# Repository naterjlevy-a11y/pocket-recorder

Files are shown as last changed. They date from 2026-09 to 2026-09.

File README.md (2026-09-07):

# Pocket Recorder

A thing in your pocket. Squeeze it, talk, let go. The note is on your phone
before you've put it away.

This repo is the industrial design and the mechanical packaging for that object,
plus a web app that does the software half. **The hardware is designed and
costed, not built.** Everything below says which is which.

---

## Why it isn't an always-on recorder

The AI wearables on sale right now record continuously, and that one decision
drives every other problem they have. It records everyone around you. It forces
a subscription, because transcribing all day is expensive. It forces a battery
big enough to run all day. And it makes people visibly uncomfortable, which
shows up in the reviews.

Deliberate capture is a different object:

| | Always-on pendant | This |
| --- | --- | --- |
| Privacy | records everyone, always | records only while held |
| Battery | must survive a day of recording | idle 99.9% of the time |
| Transcription cost | hours per day | seconds per day |
| Subscription | structurally required | optional |
| Social friction | high | it's a voice memo button |

It is not a smaller version of the always-on thing. It's the voice memo app,
minus unlocking your phone.

---

## The mechanical problem

The whole design is one question: **does it fit in a bar small enough to forget
you're carrying?**

Target is **6 × 6 × 35 mm** in drawn 316L square tube. Working through it:

| | |
| --- | --- |
| Wall thickness | 0.30 mm — thinner is too fragile to carry a button boss |
| Internal cavity | 5.40 × 5.40 mm |
| Board length needed | **26.2 mm**, parts end to end with routing space |
| Caps and accent band | 9 mm |
| Spent before any battery | **35.2 mm** |

That last row is the answer to why the bar isn't 40 mm long and why the battery
is a custom stepped pouch rather than a cell: at 40 mm there is no room left for
power. The battery becomes a 4.6 mm thick step above the board and a 2.6 mm thin
step beneath it, which is what buys **3.7 hours** of talk time at a realistic
6 mA and leaves **0.67 mm** of headroom on the stack.

Every component sits at a real coordinate in [`model/bar.scad`](model/bar.scad),
which renders five ways — assembled, ghost, internals, section, exploded — so
the packing can actually be looked at rather than asserted.

### What went wrong

[`ERRATA.md`](model/ERRATA.md) is an audit of the design against itself. It found
eight errors, three of them serious. The worst:

> **The button does not work. The design is wrong.** The tactile switch is placed
> facing the front face; the pusher enters through the side face. They are
> perpendicular. The pusher would press into empty space beside the switch.

That is a geometry error that survived both the model and the parts document,
and it would have been found by a machinist or by a wasted prototype run. It is
written up rather than quietly fixed because the fix has two options with
different costs, and the choice isn't made yet.

---

## What's in here

| | |
| --- | --- |
| [`model/bar.scad`](model/bar.scad) | The parametric model. Open in OpenSCAD, change `VIEW`. |
| [`model/PARTS-AND-LAYOUT.md`](model/PARTS-AND-LAYOUT.md) | Every part with an order number, at a real coordinate, summed and checked. |
| [`model/FIT-STUDY.md`](model/FIT-STUDY.md) | Whether it fits at 5 mm and 6 mm, and what sets the wall thickness. |
| [`model/ERRATA.md`](model/ERRATA.md) | The audit. Eight errors, three serious. |
| [`model/ASSEMBLY.md`](model/ASSEMBLY.md) | Build order. |
| [`model/SHOPPING-LIST.md`](model/SHOPPING-LIST.md) | What to buy, with confidence marked per line. |
| [`model/renders/`](model/renders) | Outside, inside, sectioned, exploded. |
| [`app/index.html`](app/index.html) | The software half: hold, talk, release, note lands. |
| [`PLAN.md`](PLAN.md) | The product argument and the market it's aimed at. |

## Running the app half

`app/index.html` is a single file with no build step. Open it, or serve the
folder:

```bash
python3 -m http.server 8000 --directory app
```

## Status

Designed, costed and audited. Not manufactured. The parts list carries a
confidence mark per line because the next step spends money.

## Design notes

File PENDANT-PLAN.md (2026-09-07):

# The Bar — plan

**One line:** a slim steel bar on a chain. It looks like jewellery. Tap it, talk, let go.

Supersedes the pocket form factor in `PLAN.md`. The thesis, the software half, and the legal notes there still hold.

---

## 1. The thesis: Ray-Ban Meta logic

You walked into a Ray-Ban store with $430 wanting nice glasses. You left with smart glasses. **The tech was a bonus discovered after the object had already won.**

That is the entire strategy. Every competitor inverts it — they build a gadget, then try to make it wearable.

| | Them | This |
| --- | --- | --- |
| First impression | "what's that device?" | "nice chain" |
| Bought because | it records | it looks good |
| Worn when | you remember to | always, it's your chain |
| Off-mode | looks like a gadget | looks like jewellery |

**The test:** someone should be able to wear it for a week before anyone asks what it is. If it fails that, nothing else in this document matters.

Corollary: **it must look complete with the electronics dead.** A bar with a seam, a visible port, or a blinking LED is a gadget. Battery flat, it still has to read as a $200 chain.

---

## 2. The object

```
         ○ ── stainless chain (or leather cord)
         │
       ╔═╧═╗
       ║   ║   6 × 6 mm square section
       ║   ║   60 mm long
       ║   ║   brushed or polished 316L
       ║   ║   no visible seam, no port, no LED
       ╚═══╝
```

| Spec | Target | Note |
| --- | --- | --- |
| Section | **6 × 6 mm** | 5 mm is possible — see §4. 6 mm is the shippable one |
| Length | 55–65 mm | also happens to be a λ/2 antenna at 2.4 GHz |
| Weight | 12–18 g | heavy enough to feel real, light enough to forget |
| Material | 316L steel v1, titanium v2 | drawn square tube, not machined |
| Finish | brushed + polished SKUs | |
| Water | **IP68** | the differentiator — see §5 |
| Cord | steel chain **or leather** | leather is quieter, see §6 |

**Chain lug is a machined solid end cap, never a hole in the tube wall.** At 0.3 mm wall that's where a yanked necklace fails.

### 2a. The reference object — real dimensions

**"Slim Bar Pendant", stainless steel: 40 mm long × 4 mm wide. Shiny finish. 10:1 ratio.**

That's the target aesthetic, confirmed from the spec sheet rather than estimated. It is smaller than it looks in the worn photo.

**4 × 4 × 40 mm cannot hold this product.** At 0.3 mm wall the cavity is 3.4 mm, and the minimum PCB width is 3.3 mm — 0.05 mm of clearance per side, before an insulating liner. There is no room for a battery *beside* the board, only end-to-end, which leaves ~11 mAh. That's Oura-ring capacity, and Oura isn't recording audio.

**The move is to scale the object, not change its proportion.** The 10:1 ratio is the look; hold it and grow.

| Outer | Cavity | Battery | Ratio | |
| --- | --- | --- | --- | --- |
| 4 × 4 × 40 | 3.4 | ~11 mAh | 10:1 | ← the reference. Unbuildable |
| 4 × 4 × 55 | 3.4 | ~23 mAh | 14:1 | too spindly, board still impossible |
| 5 × 5 × 55 | 4.4 | ~38 mAh | 11:1 | aggressive but real |
| **6 × 6 × 60** | **5.4** | **~67 mAh** | **10:1** | **← same proportion, 1.5× scale** |
| 7 × 7 × 50 | 6.4 | ~66 mAh | 7:1 | reads stubby |

**Target: 6 × 6 × 60 mm.** Identical 10:1 proportion to the pendant you picked, uniformly scaled 1.5×. It should read as *the same object*, because geometrically it is one — and it carries 6× the battery of the 4 mm version.

Millimetre intuition:

| | |
| --- | --- |
| 4 mm | the reference — a stack of ~5 credit cards |
| 5 mm | thinner than a drinking straw |
| **6 mm** | **a drinking straw** |
| 8 mm | an iPhone's thickness; an Apple Pencil is 8.9 |

**Buy the actual pendant ($40) before deciding.** Hold 4 mm in your hand, then hold a 6 mm steel tube next to it. This decision should be made physically, not from a table.

**Other things the photo settles:**

- **Square section confirmed.** Two faces catch light differently — one bright, one shadowed — with a crisp edge between. It reads as a machined bar, not a round rod. Preserve that edge; it's what makes it look intentional rather than like tubing.
- **Length-to-width ratio is ~8:1.** That proportion *is* the look. Get thicker without getting longer and it becomes a USB stick.
- **It hangs from a small bail and swings freely.** It is not a fixed link in the chain. Free-hanging is the correct choice — a rigid link would fight the body and telegraph "device."
- **The chain is delicate relative to the bar.** ~4 mm links against a 7 mm bar. A heavier chain would make it look like hardware.
- **No seam, no port, no hole anywhere on the visible faces.** Everything — mic port, contacts, antenna break — has to live on the rear face or the end caps.

---

## 3. Interaction

No screen. No LED you can't see on your own chest. Two haptic ticks are the entire UI.

```
tap ──────▶ tick ──▶ recording ──▶ release ──▶ tick ──▶ synced
double-tap ▶ tick tick ──▶ hands-free, records until tapped again
```

**Input is an accelerometer, not a touch sensor.** This is settled by physics, not preference: capacitive and inductive touch-on-metal both work by sensing the metal *flex* under your finger. A 3.5 mm button in a 0.5 mm steel wall deflects **28 nanometres** — about 180× below the detection floor. Those are appliance-panel technologies and they do not scale to a 6 mm bar.

An **ST LIS2DW12** (2 × 2 mm, <1 µA) has a hardware single-tap and double-tap engine that runs while the main chip sleeps. It gives you exactly the interaction you described, and a rigid metal bar is the *best* case for it — metal transmits the tap impulse cleanly. Oura went the same way on titanium rather than fight capacitive sensing.

Free bonus: the mic can confirm taps acoustically. Two-sensor agreement ≈ no false triggers in a pocket or under a coat.

---

## 4. How thin can it actually go

**5 mm is real.** Oura Ring 4 is 7.9 × 2.88 mm — a *smaller* cross-section than 5 × 5 — fully titanium, BLE, 100 m water resistance. Your bar has more internal volume than an Oura ring.

The unlock is **don't machine it, buy tube.** 5 × 5 mm drawn stainless square tube at 0.3 mm wall is a catalogue item (the medical-needle industry stocks it by the mile). That gives a 4.4 × 4.4 mm cavity — 1.12 cm³. Machining titanium to those walls is specialist work; buying tube is not.

| | 5 mm | **6 mm** | 7 mm |
| --- | --- | --- | --- |
| Battery | 32–40 mAh | **~50 mAh** | 70–90 mAh |
| Off-the-shelf cell? | **no — 50–100k MOQ** | **yes** | no |
| PCB | 6-layer HDI, via-in-pad | 4-layer | 4-layer, easy |
| Days @ 45 min/day | ~4 | ~6 | 8–10 |

**One thing forces 6 mm: battery supply.** Below ~4.5 mm cell diameter nothing exists off the shelf except Panasonic 16 mAh pin cells. A custom cell means a 50,000-unit minimum order — a business constraint, not a physics one.

**Decision: prototype at 5 mm to prove the antenna, ship at 6 mm.** On a 60 mm bar nobody perceives the millimetre, and 6 mm is still slimmer than every competitor (Plaud NotePin's *smallest* dimension is 11 mm).

---

## 5. The obstacles, ranked honestly

### 🔴 1. The metal case is a Faraday cage — this is the whole project's risk

A sealed metal tube does not let BLE out. The cavity is a waveguide operating **14× below cutoff**, attenuating **~6 dB per millimetre**. An antenna 5 mm inside the tube is 30 dB down. It is not weak, it is disconnected.

**"Put a chip antenna inside and add a small window" is dead on arrival.** The required RF aperture at 2.4 GHz is roughly half a wavelength — 62 mm. That is the whole product. The window can't be a patch; it has to be the device.

**The fix — the metal becomes the antenna:**

```
╔═════════╗ ← 30 mm steel  ┐
║         ║                │ half-wave dipole,
╠═════════╣ ← 1–2 mm ceramic/NMT band, fed across
║         ║                │ 61 mm ≈ λ/2 at 2.45 GHz
╚═════════╝ ← 30 mm steel  ┘
```

Split the bar, feed differentially across an insulating band. Same architecture as the iPhone 4 frame. Published metal-cased smart-jewellery research measures 68 % efficiency free-space, 27 % worn on a body.

The insulating band can be made by **NMT** (plastic injected into nano-etched metal) which produces the RF break *and* the waterproof seal in one operation.

**Budget for 2–3× range loss vs a plastic case.** Fine for a phone in your pocket. Not fine if you want 10 m. And skin contact detunes it — plan a thin dielectric coating so the radiator never touches you galvanically.

**Prototype this first. Before industrial design, before firmware.** If the split-bar antenna doesn't work, the product is plastic and the whole premise changes.

*Read: Oura patent US 11,349,191 — they make the battery housing itself the radiator.*

### 🟠 2. Battery: 50 mAh is the whole budget

Only push-to-talk makes this possible. Always-on at 5–6 mm would need charging twice a day — that is why every always-on competitor is a fat pendant.

| | |
| --- | --- |
| Standby (~45 µA) | weeks |
| 45 min recording/day | ~6 days |
| Continuous recording | ~5 h |

Storage caps at **32 MB NOR** (no SPI NAND package is small enough) ≈ 3 h of Opus. Conveniently matches the battery, so the design is self-consistent.

### 🟠 3. The microphone, dangling on your chest

Three separate problems:

**a. Structure-borne chain noise.** A metal bar rigidly coupled to a metal chain is a *contact microphone for the chain*. Every link tick goes straight into the diaphragm, louder than your voice.
→ **Never hard-mount the mic.** Suspend it on a compliant silicone boot. Highest-leverage mechanical decision in the build.
→ **Offer a leather cord SKU.** It is dramatically quieter than steel, and it's a legitimate second aesthetic rather than a compromise.

**b. Distance and off-axis.** Sternum to mouth is ~25–30 cm, and the mouth is above and behind. The physics is fine — 69 dB SPL at 30 cm against a 65 dBA-SNR mic is ~40 dB SNR before room noise. The losses are chin/chest shadowing and clothing rustle, not mic sensitivity.
→ **Two mics ~40 mm apart with beamforming** (a wearable array demonstrates ~16.5 dB SNR gain on the wearer's voice). Port angled up.

**c. The acoustic port.** A long narrow tunnel through thick metal becomes a resonator that wrecks the speech band.
→ **0.3 mm drawn tube makes this a non-issue** — Helmholtz lands at ~33 kHz, out of band. Bond the mic directly to the port with a thin gasket. Every extra millimetre of standoff makes it worse.

**Push-to-talk does the rest for free.** The mic is live only while you're deliberately holding still to speak. An always-on device has to survive a jog; this only has to survive standing still for 20 seconds. Gate on the IMU you already have — flag noisy segments rather than silently producing garbage.

### 🟡 4. Charging — you're right about the ritual, wrong about the technology

Your instinct is correct: **people already take chains off at night.** Drop it in a dish, it charges. That ritual is the product's charging story and it's better than a cable.

But true wireless is the wrong way to get it:

| | Verdict |
| --- | --- |
| **Qi** | dead — smallest coils are 10–13 mm, and the metal body kills it |
| **NFC-WLC** (ROHM ML7670, 13.56 MHz) | exists, built for smart rings, but needs ferrite shielding that eats 0.3 mm of a 4.4 mm cavity, and competes with the antenna for the same dielectric window |
| **Magnetic dock + contacts** | **✓ same ritual, a fraction of the risk** |

**A magnetic cradle delivers the exact UX you described** — plop it down, it snaps and charges — with none of the coil problems. Oura ships **exposed charging contacts at 100 m water resistance**, so contacts are not a sealing compromise. Gold or rhodium plating (sweat drives electrolysis on cheap plating), and keep the pads unpowered until the dock detects a valid load.

Bonus: make them **4 contacts** and the dock also becomes your high-speed data offload — 32 MB in ~2 minutes, instead of pushing audio through a metal-attenuated BLE link.

### 🟡 5. Waterproofing — nobody in this category has done it

Limitless Pendant: IP54. Plaud NotePin: no IP rating, explicitly not submersible. **This is an open differentiator**, and it's the difference between "take it off before the shower" and "never think about it."

Parts are off the shelf: **Gore GAW334** acoustic vent, 1.6 mm, IP68-rated, <2 dB loss at 1 kHz. Seam by NMT bond or adhesive plus full epoxy potting — Oura hits 10 ATM with glued shells. **Avoid O-rings**; there's no room for a gland in a 0.3 mm wall.

### 🟡 6. Recording law

Unchanged from `PLAN.md` §8. Canada is one-party. California, Washington, Illinois, Florida are all-party consent. Deliberate self-capture is the safe case — get the marketing copy right before shipping, not after.

---

## 6. Architecture

```
   ┌── end cap + chain lug (machined solid) ──┐
   │  [ mic A ]                               │  ← compliant boot, ported up
   │  ═══════════════════════════════════════ │
   │  [ nRF54L15 ][ flash ][ LIS2DW12 ][ PMIC ]│  ← 3.5 mm rigid-flex, 4-layer
   │  ═══════════════════════════════════════ │
   │  [ ~50 mAh cell ]                        │
   │  [ mic B ]                               │  ← beamforming pair
   └── ceramic/NMT band = antenna feed ───────┘
          └─ 4 pogo pads on rear face ─┘
```

| Function | Part | Size |
| --- | --- | --- |
| SoC | **Nordic nRF54L15** CSP47 | 2.45 × 2.25 mm |
| | *(nRF52840 WLCSP is 3.5 × 3.6 — too wide. Different chip from `PLAN.md`.)* | |
| Mic ×2 | TDK T5837, flex tail, adhesive-bonded to port | 3.5 × 2.65 × 0.98 |
| Storage | Winbond W25Q128JW WLCSP (16 MB) or MX25U256 (32 MB) | 2.5 × 2.5 |
| Input | ST LIS2DW12 tap engine | 2.0 × 2.0 |
| Power | Nordic nPM1100 | 2.1 × 2.1 |
| Codec | Opus 16 kHz mono, ~20 kbps (nRF54L15 has the RAM; nRF52 didn't) | — |
| Antenna | split-bar dipole fed across ceramic band | — |
| I/O | 4 pogo pads: charge + offload | — |

**Wiring principle: the chain load never reaches a solder joint.** Board floats on a compliant mount inside the tube; lugs tie into machined end caps. Watch-case logic.

**Store and forward, never stream.** BLE carries control and status only — a few hundred bytes that punch through a marginal metal link fine. Audio goes over the dock. A dropped connection mid-sentence must never cost a note.

---

## 6a. The app

**Design goal: the ideal number of app opens per day is zero.** The bar captures, the phone routes, the note lands where it belongs. The app is a safety net you check occasionally — not a destination. Every screen below exists for when something went wrong or you want to look back.

This is the opposite of Plaud, whose app *is* the product and where every note is a trip into their walled garden.

### The happy path — no app involved

```
tap ─▶ "note to self, order the L298N" ─▶ release
  │
  ├─ device: encode, write to flash, BLE notify "1 pending"
  │
  ├─ phone wakes in background (no unlock, no open)
  │    pull audio ─▶ transcribe on-device ─▶ clean ─▶ parse routing phrase
  │
  └─ lands in Apple Notes. Silent. ~10 s after you stopped talking.
```

You never saw a screen. That's the product.

### Screens

**1. Inbox** — the default and usually the only one.

Reverse-chronological cards. Each shows transcript preview, duration, time, and a **destination badge** (`Notes` · `Reminders` · `Claude` · `Unrouted`). Pull to sync. That's it.

The badge is the important bit — it tells you at a glance that the thing already went where it should, so you can close the app.

**2. Note detail** — transcript, audio scrubber, edit, re-route, delete. Raw and cleaned text both available; people distrust cleanup they can't inspect.

**3. Routing rules** — the differentiator, and the only screen worth real design effort.

| Phrase | Destination |
| --- | --- |
| "note to self…" | Apple Notes |
| "remind me to…" | Reminders (parse the time) |
| "hey Claude…" | clipboard / Claude, waiting on the laptop |
| "add to \<list\>…" | that list |
| *(no phrase)* | Inbox, unrouted |

User-editable. Ships with sensible defaults. Fork Cadence's parser.

**4. Device** — battery %, notes pending, storage, last sync, firmware. Boring on purpose. Also where tap sensitivity gets calibrated.

**5. Onboarding** — pair, tap-calibrate (tap it three times so the threshold fits how *you* tap and what you wear it over), choose destinations, record one test note end-to-end. Under two minutes.

### The states that actually matter

Most of the app's difficulty is not screens, it's these:

| State | Behaviour |
| --- | --- |
| Phone out of range | Device holds it. Nothing is lost. Badge shows pending count on next connect |
| Sync interrupted | Chunked and resumable. **Verify-then-erase** — never delete from device until the phone confirms the write |
| Transcription uncertain | Flag it. Show confidence; don't silently ship garbage |
| Recorded while moving | IMU flags the segment: "this one was noisy" |
| No routing phrase heard | Land in Inbox unrouted rather than guessing wrong |
| Device full | Warn at 80 %, refuse new recordings at 100 % rather than overwrite |

**The rule: it is always better to surface an uncertain note than to silently lose or misfile one.** Trust in a capture device is destroyed exactly once.

### Why this is the easy half

Cadence already does push-to-talk capture, on-device Apple Speech transcription, rule-based cleanup, routing-phrase parsing, and delivery to a named destination. **The phone pipeline is written and shipped.** What's new is the BLE transport layer and the inbox UI — genuinely the smaller job, which is why the hardware risk in §5 deserves the attention.

---

## 7. Build order

| Phase | What | Gate |
| --- | --- | --- |
| **0** | **Split-bar antenna rig.** Steel tube, ceramic band, nRF dev board, measure range on-body. **~$150.** | Does BLE get out? If no, the product is plastic — find out now |
| **1** | XIAO + LIS2DW12 taped to a steel bar on a chain. Tap detection + chain-noise recording. | Does tap-vs-double-tap work? Is chain noise survivable? |
| **2** | Mic port + compliant mount test on printed shells. Record walking, sitting, talking. | Is transcription usable at chest distance? |
| **3** | Cadence integration — BLE sync, on-device transcription, routing. Software half already exists. | End-to-end note in under 10 s |
| **4** | Custom 3.5 mm rigid-flex, 5 boards. | |
| **5** | 6 mm steel tube bodies, 20 units, real people. | |

**Phases 0–2 are the whole risk and cost under $400.** Antenna, tap, mic. Everything after is execution.

**Wear the ugly version for a month before spending real money.** If you don't reach for it, industrial design won't save it.

---

## 7a. What to order now

**Phase 0 cart — ~$180.** Everything needed to answer the antenna question and feel the size.

| Item | Why | ~$ |
| --- | --- | --- |
| **The actual Slim Bar Pendant (40 × 4 mm)** | hold the target. Decide 5 vs 6 mm physically | 40 |
| **316 stainless square tube**, 5×5 and 6×6, 0.3–0.5 mm wall, 300 mm | the body. Buy both, cut, compare on your chest | 25 |
| **Seeed XIAO nRF52840 Sense** | mic + IMU + charging on board. Phase 0/1 brain | 20 |
| **Zirconia or PTFE rod**, 5–6 mm dia | the insulating antenna band | 15 |
| 150 mAh LiPo (bench, not final) | power the rig | 8 |
| Chain + bail assortment | **ask the Vancouver wholesaler** — see below | ~0 |
| Copper tape, thin coax/RG-178 pigtail, SMA | feed the split-bar dipole | 25 |
| Silicone sheet 0.5 mm, acoustic mesh | compliant mic boot | 10 |
| Digital calipers (if you don't have them) | non-negotiable for this project | 25 |

**Nice to have:** a **nRF52840 dongle** (~$10) as a BLE sniffer/RSSI meter — it turns "does the antenna work" from a guess into a measurement.

### The jewellery connection is a real asset — use it early

A wholesale jewellery supplier in Vancouver gets you, in rough order of value:

1. **Chains and bails at cost**, in the exact gauges that look right — the photo's chain is ~4 mm rolo, and chain choice changes the whole read of the object.
2. **A finisher.** Someone who already brushes, polishes, and PVD-coats steel. This is the difference between "machined part" and "jewellery," and it is not something you can do at home.
3. **Manufacturing vocabulary and contacts** — casting, plating, tumbling, laser engraving. The pendant is described as engravable; that's a personalisation SKU for free.
4. **A retail channel and a reality check.** Show them the bar. If a jeweller says it reads as a gadget, that's the cheapest negative feedback you will ever get.

**Ask specifically for:** hollow/tube stock sources, whether they can polish a 6 mm tube end-to-end, and what a 4 mm vs 6 mm bar does to perceived price.

### CAD — yes, but not first

You'll need a model, but not before Phase 0. Sequence:

1. **Stack-up sketch first** (paper or a 2D sketch). Blocks on a line: end cap · mic · PCB · battery · antenna band · end cap. Sum the lengths. If they don't add up to 60 mm, no amount of CAD helps.
2. **Fusion 360** (free personal/startup licence) for the body. Model the tube, both end caps, the bail lug, mic port, and the contact pads.
3. **Import the board as a STEP** once there's a PCB — Fusion and KiCad round-trip this, and it's the only reliable way to catch a component colliding with a wall.
4. **Print the shell in resin at 1:1** before cutting any steel. A $2 print catches proportion mistakes that a $200 tube can't un-cut.

**Model the internal stack-up before the external shape.** The outside is 30 minutes of work; the inside is where it fails.

---

## 8. Money

| | |
| --- | --- |
| Phases 0–2 (the real questions) | **~$400** |
| Custom boards | ~$600 |
| 20 units | ~$2,500 |
| Steel tube @ volume | pennies + $8–20/unit finishing |
| NMT / ceramic band tooling | the real cliff — quote it at phase 4 |

Metal costs more than plastic and is non-negotiable. It's the product.

---

## 9. Decisions needed

1. **Steel or titanium for v1?** Steel is cheaper and buyable as tube; titanium is lighter, more hypoallergenic, and 1–3 dB better for RF.
2. **Leather cord as launch SKU or v2?** Acoustically it's the better answer, and it may be the better-looking one.
3. **Brushed or polished first?** Polished shows every scratch on something that swings into door frames.
4. **Does it need to be 5 mm?** 6 mm ships this year. 5 mm needs a 50k-unit battery order.

---

## 10. Next action

Order 5 × 5 mm and 6 × 6 mm stainless square tube (0.3–0.5 mm wall), a ceramic spacer, and build the phase-0 antenna rig against a dev board.

**Everything else in this plan is downstream of one question: can BLE get out of a steel bar.**

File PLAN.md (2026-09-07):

# Pocket note-taker — plan

**One line:** a thing in your pocket. Squeeze it, talk, let go. The note is on your phone before you've put it away.

---

## 1. The strategic point, first

The AI-wearable market right now is **always-on life recorders**, and that category has a problem it can't design its way out of: it records everyone around you, all the time. That forces a subscription (constant cloud transcription is expensive), it forces big batteries, and it makes people uncomfortable in a way that shows up in every review.

**Deliberate capture is a different product.** Push-to-talk means:

| | Always-on pendant | This |
| --- | --- | --- |
| Privacy | records everyone, always | records only when you press it |
| Battery | must last all day recording | idle 99.9% of the time — weeks |
| Transcription cost | hours per day | seconds per day |
| Subscription | structurally required | optional |
| Storage | gigabytes | megabytes |
| Social friction | high | none — it's a voice memo button |

That is the whole thesis. It isn't a smaller version of a Limitless Pendant; it's the thing people actually reach for, which is the voice memo app, minus unlocking your phone.

### The market as of now

| Product | Price | Model | Status |
| --- | --- | --- | --- |
| **Plaud Note** | ~$159–179 | card-shaped, deliberate capture, subscription tiers | the one to beat |
| **Bee** | $49.99 + $19/mo | always-on pendant | $278 in year one |
| **Omi** | $89 | always-on pendant | open-ish ecosystem |
| **Limitless Pendant** | — | always-on pendant | **acquired by Meta Dec 2025, no longer sold** |

Limitless being absorbed and shut down is the opening. It removed the best-designed competitor from the market and stranded its users.

**Plaud is the real competitor** and it's already deliberate-capture. Differentiation has to be sharper than "same but cheaper":
- **No subscription for the base loop.** Transcription on-device on the phone (Apple Speech / Android SpeechRecognizer) is free and offline. Charge only for the cloud/LLM tier.
- **One-hand, eyes-free, in-pocket.** Plaud is a card you take out and look at. This is a squeeze you never look at.
- **It goes somewhere.** See §6 — this is the part nobody else has.

---

## 2. What it does

```
squeeze ─▶ haptic tick ─▶ you talk ─▶ release ─▶ haptic tick
                                                     │
                                          stored + compressed on device
                                                     │
                                    BLE sync when phone is in range
                                                     │
                              transcribed on phone, on-device, free
                                                     │
                                       lands where you told it to go
```

No screen. No app to open. The interaction is one button and two haptic ticks, so it works in a pocket, in a bag, walking, mid-conversation.

**Store-and-forward, not streaming.** The device records to its own flash and syncs later. This matters: it works when your phone is in another room, in a bag, or dead. A streaming device is useless the moment it's out of range, and it burns radio power constantly.

---

## 3. Hardware

### Prototype — build this first, it's a weekend

| Part | Why | Cost |
| --- | --- | --- |
| **Seeed XIAO nRF52840 Sense** | nRF52840 + **PDM mic already on board** + IMU + LiPo charging, 21×17.5mm | ~$20 |
| LiPo 3.7V 400 mAh | ~2 weeks idle, plenty of recording | ~$8 |
| Momentary tactile switch | start here, not capacitive — see below | ~$1 |
| Coin vibration motor | the haptic tick | ~$2 |
| 3D-printed shell | — | ~$5 |
| Wire, JST connector | — | ~$5 |
| **Total** | | **~$40** |

The XIAO Sense is the reason to start here rather than designing a board: the microphone and the battery charger are already on it, so the prototype is a battery, a button and a motor soldered to a $20 board. You can have a working device before committing to any layout.

**Why nRF52840 over ESP32-S3:** 5 µA deep sleep vs ~14 µA, and far more importantly the ESP32 pulls 80–100 mA with the radio active against the nRF's near-negligible BLE overhead. For a device that idles 99.9% of the time and wakes for 20 seconds, that difference is weeks of battery versus days. ESP32-S3 only wins if you need Wi-Fi, and you don't — the phone is the uplink.

**Button, not capacitive touch, for v1.** Capacitive feels premium and fails in a pocket: fabric, moisture and body capacitance all trigger it. A real switch with a defined click is eyes-free, gives tactile confirmation, and cannot false-fire against your leg. Revisit for v2 with a force sensor if the click feels cheap.

### Production BOM (per unit)

| Part | @100 | @1,000 |
| --- | --- | --- |
| nRF52840 module (Raytac/Fanstel) | $6.00 | $4.50 |
| MEMS mic (ICS-43434 / SPH0645, I²S) | $1.50 | $1.10 |
| 32 MB SPI flash (W25Q256) | $1.50 | $1.00 |
| Charge IC + protection (BQ25101 + DW01) | $1.00 | $0.70 |
| LiPo 400 mAh | $3.00 | $2.00 |
| USB-C receptacle | $0.30 | $0.18 |
| LRA haptic + driver (DRV2605L) | $1.60 | $1.10 |
| Switch, LED, passives | $1.50 | $0.90 |
| PCB, 4-layer, ~25×45mm | $2.00 | $0.80 |
| Enclosure | $10.00 (CNC/SLA) | $2.50 (injection) |
| Assembly + test | $5.00 | $2.50 |
| **BOM total** | **~$33** | **~$17** |

**Injection mould tooling: $3,000–8,000.** That's the cliff. Below ~500 units, 3D-print or CNC the shells and eat the $10.

At $17 landed you can sell at $79–99 with healthy margin and undercut Plaud by half.

---

## 3a. Form factor — the device as a link, not a pendant

**Reference: a men's chain, where the device closes the loop.** It isn't a pendant hanging off the chain; it *is* a section of the chain. A barrel or clasp that happens to be electronics. Every competitor is a pendant or a card. Nothing on the market is jewellery.

**Target envelope: roughly 42 × 13 × 9 mm.** Read as a chunky clasp or a barrel bead. For comparison the Bee pendant is ~30 × 30 × 10 mm and reads unmistakably as a gadget.

### Does it fit? Yes, and only because of push-to-talk.

| Part | Footprint |
| --- | --- |
| Raytac MDBT50Q (nRF52840 module) | 10.5 × 15.5 × 2.2 mm |
| ICS-43434 MEMS mic | 3.5 × 2.65 × 1.0 mm |
| W25Q256 flash (WSON-8) | 6 × 5 × 0.8 mm |
| Charge IC + protection | ~3 × 3 mm each |
| LRA haptic | 10 × 3 mm |
| **Battery — the real constraint** | see below |

A 42 × 13 × 9 mm barrel leaves roughly **4 × 11 × 20 mm** for a cell after walls and board. That's a **401120 pouch, ~90 mAh**.

90 mAh sounds fatal. It isn't:

| | |
| --- | --- |
| Idle at 10 µA | **375 days** |
| Real use, 20 notes/day at 30 s | **~38 days** |
| Charge time | under an hour |

**This is the payoff of the deliberate-capture thesis.** An always-on recorder at ~8 mA continuous would drain this cell in **11 hours** — which is exactly why every always-on competitor is a fat pendant. Push-to-talk is what makes jewellery-scale possible. The form factor and the product thesis are the same decision.

### The microphone problem — the hardest part of the build

You identified this yourself and you're right that it's the thing that kills it. A mic rigidly mounted inside a metal shell attached to a metal chain is a **contact microphone for the chain**. Every link tick conducts straight into the diaphragm as structure-borne noise, and it will be louder than your voice.

Four things fix it, in order of importance:

1. **Never hard-mount the mic to the shell.** Suspend it on a compliant silicone boot or gasket so the mechanical path from shell to mic is broken. This is the single highest-leverage mechanical decision in the whole device.
2. **Port upward, toward the mouth**, not outward. A chain sits at the sternum; the mouth is ~25 cm up and behind. An upward port with a short, sealed acoustic channel beats a bigger mic in the wrong place, every time.
3. **Push-to-talk does most of the work for free.** The mic is only live while you're deliberately holding the button, and people naturally still themselves to speak. An always-on device has to survive a jog; this one only has to survive standing still for 20 seconds.
4. **Use the IMU you already have.** The XIAO Sense has a 6-axis IMU. Flag segments recorded during high motion so the app can warn "this one was noisy" instead of silently producing garbage transcript.

Acoustic mesh over the port for wind and lint. Test the port geometry on a printed shell **before** committing to a board layout — this is the thing most likely to force a redesign.

### Interaction

**Squeeze, not press.** Button on the back, thumb braced on the front. On a chain-mounted barrel that's the only gesture that works one-handed without lifting the device to look at it, and it doesn't yank the chain against your neck.

- **Press and hold** = record while held. Unambiguous, no state to forget, matches Cadence exactly.
- **Double-click** = hands-free mode, records until clicked again, for longer thoughts.
- Two haptic ticks: one on start, one on stop. **No LED as the primary feedback** — you can't see your own chest.

### Charging: magnetic pogo pins, not USB-C

A USB-C receptacle is ~8.9 mm wide and needs a hole in the shell. On a 13 mm-wide piece of jewellery that's most of the width and a water ingress path.

**Two pogo pads on the back and a magnetic cable.** It lets the shell be effectively seamless, survives sweat, and is what every piece of wearable jewellery does. It also costs less board area.

### Drop Wi-Fi

You mentioned Wi-Fi as an option. Don't. The nRF52840 has no Wi-Fi radio, adding one means a second chip, and Wi-Fi's power draw is incompatible with a 90 mAh cell. **BLE only.** The phone is the uplink; it already has Wi-Fi.

### Mechanical: the load path

The chain pulls on this thing all day. **The anchor points must tie into the shell, not the PCB.** Two machined lugs at each end, with the board floating inside on a compliant mount so no chain load ever reaches a solder joint. This is how a watch case works and it's the difference between a product and something that fails in a month.

Shell: **CNC stainless or brushed aluminium** at low volume. It's jewellery, it will be judged as jewellery, and a printed plastic shell reads as a prototype no matter how good the electronics are.

### What this changes about cost

CNC metal shells at low volume run **$15–25/unit** rather than the $10 printed estimate in §3, and the smaller cell saves about a dollar. Call it **~$40/unit at 100**, versus $33 for the plastic pocket version. At 1,000 with tooling it converges back toward $20.

The metal shell is worth it. It's the difference between a gadget and something someone wears.

---

## 4. Firmware

**nRF Connect SDK (Zephyr).** Nordic's own stack, best-documented path for this chip.

```
button ISR ─▶ wake from System OFF
           ─▶ haptic tick
           ─▶ PDM/I²S mic on, 16 kHz mono
           ─▶ encode ─▶ ring buffer ─▶ SPI flash
release    ─▶ haptic tick, close the record, sleep
BLE        ─▶ on connect: advertise pending notes, transfer, verify, erase
```

**Codec — the one real engineering decision.**

| Option | Bitrate | 60s note | CPU | Verdict |
| --- | --- | --- | --- | --- |
| Raw PCM 16k/16-bit | 256 kbps | 1.9 MB | none | too big |
| **IMA ADPCM 4:1** | 64 kbps | 480 KB | trivial | **start here** |
| Opus 16 kHz | 24 kbps | 180 KB | heavy on M4F | v2 target |

Start with ADPCM. It's ~20 lines, costs nothing, and 32 MB of flash still holds **~65 one-minute notes**. Opus is 2.6× better but it's a real port and it eats the CPU budget on a 64 MHz M4F. Don't fight that battle before the product exists.

**Power budget** (400 mAh):
- Deep sleep: ~10 µA → months
- Recording: ~8 mA → ~50 hours of actual talking
- BLE sync: ~7 mA in bursts

Realistically **3–6 weeks per charge** at 20 notes/day. That is the number to advertise, and it's a category-beating one precisely because the thing isn't always on.

---

## 5. The phone app

**React Native or Flutter**, one codebase.

1. **BLE sync** — background transfer, chunked, resumable, verify-then-erase. Never delete from the device until the phone confirms the write.
2. **Transcription — on-device by default.** `SFSpeechRecognizer` with `requiresOnDeviceRecognition = true` on iOS; `SpeechRecognizer` on Android. **Free, offline, private.** This is the whole reason there's no mandatory subscription.
3. **Cleanup** — fillers out, punctuation and capitals in, deterministic rules first.
4. **Routing** — where the note goes.

**The base product must work fully offline with no account.** Cloud LLM summarising, search across notes, and multi-device sync are the paid tier. If the free tier is genuinely useful, the paid one sells itself; if the free tier is crippled you're Bee, charging $19/month.

---

## 6. Why you specifically should build this

**You already built the software half.** Cadence is a push-to-talk capture app that transcribes on-device with Apple Speech, cleans the text with rule-based passes, parses a routing phrase out of the speech, and delivers it to the right destination. That is *exactly* this product's phone-side pipeline, already written, already shipped, already notarised.

The device is the missing front-end for something you've already built.

And it gives the product the thing no competitor has: **notes that route themselves.** Squeeze it and say *"note to self, buy the L298N"* and it lands in your notes. Say *"hey Claude, why did the servo jitter"* and it's a prompt waiting on your laptop. Plaud gives you a transcript in Plaud's app. This puts the thought where the thought belongs.

That's the pitch, and it comes from work you've already done.

---

## 7. Build order

| Phase | What | Time | Cost |
| --- | --- | --- | --- |
| **0** | XIAO + button + battery on a breadboard. Record on press, dump WAV over USB. Proves mic, storage, power. | a weekend | $40 |
| **1** | Add BLE transfer. A crude phone app that receives a file and plays it. **The riskiest part — do it early.** | 1–2 weeks | $0 |
| **2** | Transcription on the phone. Fork Cadence's cleanup and routing logic. | 1–2 weeks | $0 |
| **3** | 3D-printed shell, LiPo, haptics. A thing you carry for a month. **Carry it. The month is the point.** | 2 weeks | $60 |
| **4** | Custom PCB, 5 boards from JLCPCB. | 3–4 weeks | ~$300 |
| **5** | 20 units to real people. | 6 weeks | ~$1,000 |

**Phase 3 is the decision gate.** Carry it every day for a month. If you don't reach for it, no amount of industrial design saves it — and you'll have spent $100 instead of $10,000 finding that out.

---

## 8. What will actually go wrong

1. **BLE throughput.** Practical is ~100–300 kbps, well under the theoretical 2 Mbps. A 480 KB note takes ~20–40 seconds. Fine for notes, fatal for hours of audio — another reason the deliberate-capture model is the right one.
2. **Microphone placement.** The single biggest determinant of transcription quality, and it's mechanical, not software. A mic port sealed by fabric or a badly-designed acoustic path ruins everything downstream. Prototype the port before the enclosure.
3. **iOS background BLE.** Restrictive. Needs the right background modes and state restoration, and Apple will ask why during review.
4. **Recording law.** You're building a recording device. Canada is one-party consent, so recording yourself is unambiguous. Several US states (California, Washington, Illinois, Florida) are **all-party consent** — recording a conversation without everyone's agreement is a crime there. Deliberate capture of your own voice is the safe case and another reason not to build an always-on recorder. Get this right in the marketing copy before you ship, not after.
5. **Battery certification.** Shipping lithium cells across borders means UN38.3 testing and specific packaging. Budget for it before you sell internationally.
6. **You'll want to add a screen.** Don't. The absence of a screen is the product.

---

## 9. Money

| | |
| --- | --- |
| Get to a carryable prototype | **~$150** |
| Get to 5 custom boards | **~$450** |
| Get to 20 sellable units | **~$1,500** |
| Injection tooling (only past ~500 units) | **$3,000–8,000** |

You can reach a real, wearable, working device that syncs to your phone for **under $200** — and that's the only milestone that matters, because it's the one that tells you whether the idea is right.

---

## 10. Next action

Order a **Seeed XIAO nRF52840 Sense**, a **400 mAh LiPo**, and a **tactile switch**. About $30. Phase 0 needs nothing else, and the on-board microphone means you can test the single most uncertain thing — whether audio quality from a pocket is good enough to transcribe — before designing anything at all.

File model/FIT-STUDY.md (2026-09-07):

# Fit study — does everything actually go in the box?

Built the box, put every part in it, checked the margins. **Short answer: yes at 6 mm, no at 5 mm, and only if the battery is a flat pouch under the board rather than a round cell behind it.**

---

## 1. The number that drives everything

The circuit board needs **26.2 mm of length**. That isn't negotiable — it's the parts laid end to end with routing space between them:

| On the board | mm |
| --- | --- |
| Processor (nRF54L15) | 2.45 |
| Flash | 2.5 |
| Charger | 1.6 |
| 32 MHz crystal | 1.6 |
| Tactile switch | 2.0 |
| Mic + silicone boot | 3.5 |
| ~12 passives | 6.0 |
| Indicator LED | 1.0 |
| Spacing between parts | 5.6 |
| **Total** | **26.2** |

Add the two end caps and the accent band — **9 mm** — and you've spent **35.2 mm before a single milliamp-hour of battery.**

That's the whole problem with a 40 mm bar.

---

## 2. Wall thickness — 0.3 mm is the answer

| Width | Wall | Cavity | 3.6 mm board fits? |
| --- | --- | --- | --- |
| 5 | 0.2 | 4.6 | yes — but too fragile for a button boss |
| 5 | 0.3 | 4.4 | yes |
| 5 | 0.4 | 4.2 | yes, barely |
| 5 | **0.5** | 4.0 | **NO** |
| 6 | 0.2 | 5.6 | yes — too fragile |
| **6** | **0.3** | **5.4** | **yes, comfortably** |
| 6 | 0.4 | 5.2 | yes |
| 6 | 0.5 | 5.0 | yes |

**0.2 mm is too thin** — the button needs a local thickened boss to hold the O-ring groove, and there's nothing there to thicken. **0.5 mm at 5 mm wide kills the board.** 0.3 mm is a standard drawn-tube size and leaves room for the button.

---

## 3. Layout A — round cell behind the board (what a 60 mm bar does)

The cell and the board sit end to end, so they compete for length directly.

| Width | Length | Battery space | mAh | Days @15 min/day |
| --- | --- | --- | --- | --- |
| 6 | **40** | 4.8 mm | **2.6** | **2** ← dead |
| 6 | 50 | 14.8 mm | 12.0 | 9 |
| 6 | 60 | 24.8 mm | 21.3 | 16 |
| 6 | 70 | 34.8 mm | 30.7 | 23 |
| 5 | 60 | 24.8 mm | 13.2 | 10 |

**At 40 mm this layout is dead** — 4.8 mm of leftover space is about 2 mAh. This layout needs 55 mm minimum.

---

## 4. Layout B — flat pouch *under* the board ← the unlock

A pouch cell 2.6 mm thick slides beneath the board instead of behind it. Board stack is 2.2 mm tall, pouch is 2.6 mm, total 4.8 mm — fits inside a 5.4 mm cavity. **Now they overlap along the length instead of competing for it.**

| Width | Wall | Length | Pouch | mAh | Days @15 min/day |
| --- | --- | --- | --- | --- | --- |
| 6 | 0.3 | **40** | 4.8 × 2.6 × 30 | **15.7** | **12** |
| 6 | 0.3 | 45 | 4.8 × 2.6 × 35 | 18.3 | 14 |
| 6 | 0.3 | 50 | 4.8 × 2.6 × 40 | 20.9 | 16 |
| 5 | 0.3 | 40 | 3.8 × 1.6 × 30 | 7.6 | 6 |
| 5 | 0.3 | 45 | 3.8 × 1.6 × 35 | 8.9 | 7 |

**6 mm × 40 mm gives 15.7 mAh — about 12 days at 15 minutes of talking a day.** That works.

**5 mm gives half that**, because losing 1 mm of width costs 1 mm off *both* the pouch's width and its thickness. Cross-section is squared, not linear — this is why 5 mm keeps failing.

---

## 5. The catch — and the fix

Layout B has one consequence that changes the outside of the product.

The board and battery now span nearly the whole body. But **nothing conductive can cross the antenna gap**, or the two steel halves short together and the radio dies. With the internals filling the body, there's nowhere in the middle to put a split.

**So the RF window moves to the end.** Instead of a thin band at the midpoint, make the **bottom 7 mm a solid black dielectric tip** — ceramic or polymer — with the antenna inside it. The 33 mm metal body above becomes the counterpoise, and at 2.45 GHz a quarter wave is 30.6 mm, so a 33 mm body is very close to ideal for that job.

This is arguably a better-looking object than a thin band: a polished steel bar with a black tip. It also still does every job you wanted:

| You wanted | The tip delivers |
| --- | --- |
| Black accent near the bottom | it *is* the bottom |
| Lets Bluetooth through | it's the antenna window |
| Light can glow through it | translucent polymer + one LED |
| Waterproof but sound passes | ePTFE mesh face over the mic port |

**A thin mid-body band only works with Layout A** — the 55–60 mm version with a round cell. Both are valid; they're just different products.

---

## 6. Recommendation

**6 mm square · 0.3 mm wall · 45 mm long · flat pouch under the board · black dielectric tip at the bottom.**

| | |
| --- | --- |
| Cavity | 5.4 × 5.4 mm |
| Board | 3.6 mm wide, 1.8 mm of margin |
| Battery | 18.3 mAh |
| Runtime | ~14 days at 15 min/day |
| Button | Ø2.6 mm pusher, side face, ~32 mm down |
| Mic | behind mesh, upper third — closest to your mouth |
| Proportion | 7.5:1, close to the 10:1 reference |

45 mm rather than 40 mm buys 17% more battery and better antenna performance for 5 mm nobody will notice. If you want to go longer, every extra 5 mm is roughly 2.6 mAh — about two more days.

---

## 7. Margins, honestly

| Check | Margin | Verdict |
| --- | --- | --- |
| Board width in cavity | 1.8 mm | comfortable |
| Board + pouch stack height | 0.6 mm | tight but real |
| Button boss inside wall | 1.8 mm | fine |
| Mic package width | 2.75 mm | plenty |
| Length budget | 45 − 35.2 = 9.8 mm spare | comfortable |

**The tight one is stack height** — 0.6 mm across board plus battery. That means the pouch must be a specified thickness with a real tolerance, not a generic part. Confirm the exact cell before finalising the tube.

**Still unproven:** whether the antenna radiates well enough out of a dielectric tip on a 33 mm metal body. That remains Phase 0 and no amount of arithmetic settles it.

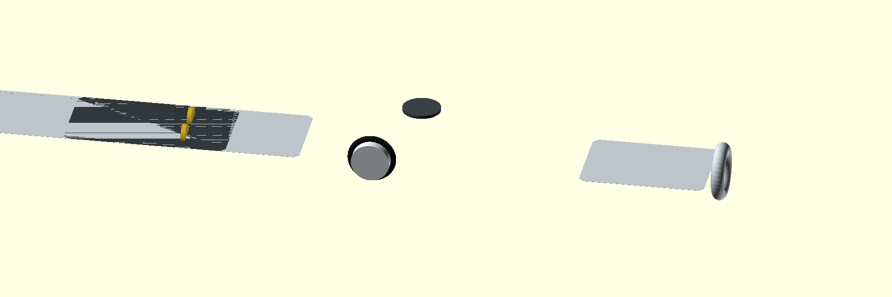
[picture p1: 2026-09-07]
model/renders/1_outside.png

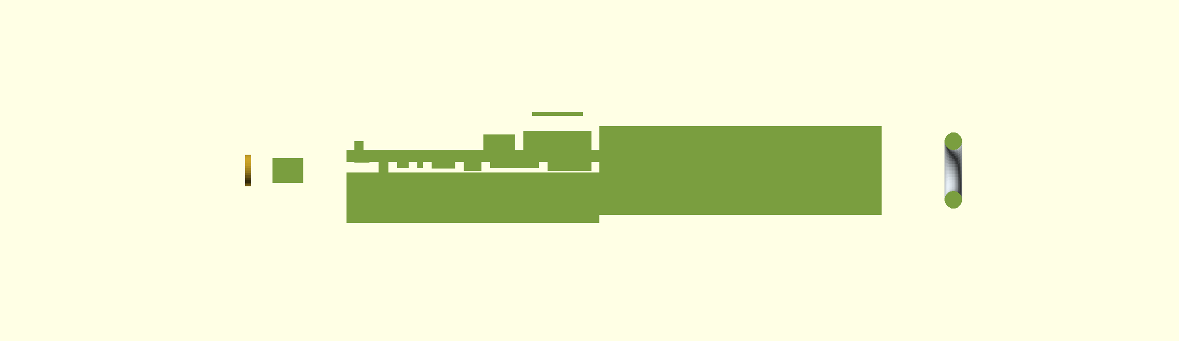
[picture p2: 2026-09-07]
model/renders/3_cut_open.png

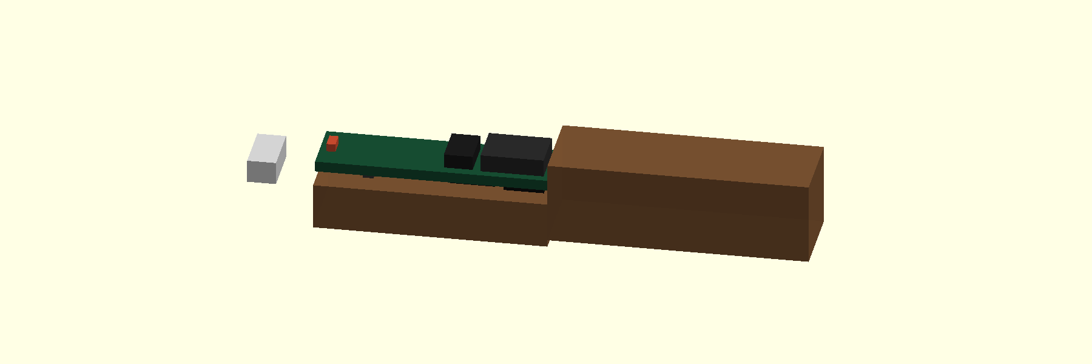
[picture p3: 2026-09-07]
model/renders/2_inside.png

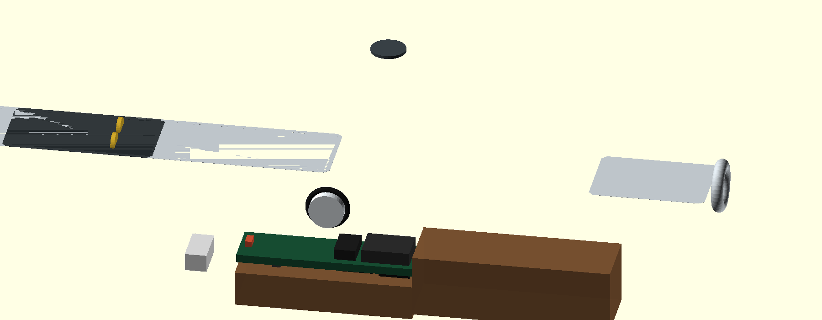
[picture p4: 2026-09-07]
model/renders/4_pulled_apart.png

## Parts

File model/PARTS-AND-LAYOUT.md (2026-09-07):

# Parts list and physical layout — 6 × 6 × 35 mm

Every part with a real order number, placed at real coordinates, summed and checked. **It fits, with 0.67 mm of headroom.**

---

## 1. The bar

| | |
| --- | --- |
| Outside | 6.00 × 6.00 × 35.00 mm |
| Wall | 0.30 mm (drawn 316L square tube — catalogue stock) |
| Cavity | 5.40 × 5.40 mm |
| Battery | ~28 mAh custom stepped pouch |
| Talk time | **3.7 hours** per charge (realistic 6 mA) |

### Zones down the length

| Zone | From | To | Length |
| --- | --- | --- | --- |
| Top cap + chain bail | 0.00 | 2.50 | 2.50 |
| Battery only — thick step, 4.6 mm | 2.50 | 17.00 | 14.50 |
| Board over battery — thin step, 2.6 mm | 17.00 | 30.00 | 13.00 |
| Black dielectric tip (antenna + light) | 30.00 | 35.00 | 5.00 |

**The board goes at the bottom.** That's what puts the button in the lower third where you wanted it, and puts the LED next to the tip it lights.

### What you see on the outside

| Feature | Position | Face |
| --- | --- | --- |
| **Button pusher** Ø2.6 | **22.2 mm from top — 63% down** | side |
| **Mic port** Ø1.2 + Ø2.6 mesh | 19.2 mm from top | front |
| **Charge pads** 2 × Ø1.6 | bottom of the tip | bottom |
| **Black tip** | last 5 mm | wraps around |

---

## 2. Parts to order

Confidence is marked, because you're going to spend money on this.

| Part | Order number | Size mm | Job | ✓ |
| --- | --- | --- | --- | --- |
| SoC + Bluetooth | **NRF54L15-CAAA-R** (Nordic, CSP47) | 2.45 × 2.25 × 0.50 | brain and radio | verified |
| Microphone | **T5837** (TDK InvenSense) | 3.50 × 2.65 × 0.98 | picks up your voice | verified |
| Flash 16 MB | **W25Q128JW** WLCSP (Winbond) | 2.50 × 2.50 × 0.33 | holds recordings | verified |
| Charger | **BQ25100YFPR** (TI, WCSP) | 1.60 × 0.90 × 0.50 | charges the cell safely | verified |
| Crystal 32 MHz | **NX1612SA-32MHZ** (NDK) — JLCPCB C1986486 | 1.60 × 1.20 × 0.35 | clock for the radio | verified |
| Antenna | **2450AT18A100E** (Johanson) | 3.20 × 1.60 × 1.30 | in the tip | verified |
| Mic vent | **GORE GAW334** | Ø1.6 | waterproof, sound passes | verified |
| Inductor | 0402 DC-DC | 1.00 × 0.50 × 0.55 | power supply | standard |
| Passives ×9 | 0201 | 0.60 × 0.30 | supply + RF tuning | standard |
| LED | 0402 side-fire | 1.00 × 0.50 × 0.45 | lights the tip | pick colour |
| **Tactile switch** | 2.5 × 1.6 class — **confirm before layout** | 2.50 × 1.60 × 0.80 | the button | **needs choosing** |
| **Stepped cell** | Grepow custom, 4.8 wide | stepped 2.6 / 4.6 | ~28 mAh | **needs a quote** |

**Two saved parts worth knowing about:** the nRF54L15 has **crystal load capacitors built in** (settable 4–17 pF in firmware), so the usual two load caps are gone. And there's no separate audio chip, because the T5837 outputs digital data straight to the SoC.

**The two open items are the switch and the cell.** Everything else can be ordered from Digi-Key today. The stepped cell is the long-lead item — quote it first.

---

## 3. Board layout

**3.6 mm wide × 13.0 mm long**, 4-layer rigid-flex, 0.6 mm core. Populated both sides — that's what makes 35 mm possible at all; single-sided needs 25.5 mm and the bar grows to 48 mm.

X is measured from the left edge of the board. Y is measured down the board, and then down the whole bar.

### Bottom side — faces the battery, thin parts only

| Part | X from left | Y on board | Y in bar | Height |
| --- | --- | --- | --- | --- |
| nRF54L15 SoC | 0.57 | 0.40 | 17.40 | 0.50 |
| W25Q128JW flash | 0.55 | 3.10 | 20.10 | 0.33 |
| BQ25100 charger | 1.00 | 6.05 | 23.05 | 0.50 |
| NX1612SA crystal | 1.00 | 7.40 | 24.40 | 0.35 |
| RF match, 3 × 0201 | 0.90 | 9.05 | 26.05 | 0.30 |
| Decoupling, 6 × 0201 | 0.30 | 9.80 | 26.80 | 0.30 |
| Inductor 0402 | 1.30 | 10.85 | 27.85 | 0.55 |
| Programming pads | 1.20 | 11.80 | 28.80 | 0.05 |

### Top side — faces the case wall, tall parts

| Part | X from left | Y on board | Y in bar | Height |
| --- | --- | --- | --- | --- |
| T5837 microphone | 0.48 | 0.40 | **17.40** | 0.98 |
| Tactile switch | 0.55 | 4.35 | **21.35** | 0.80 |
| LED (lights the tip) | 1.30 | 12.10 | 29.10 | 0.45 |

**The microphone sets the board width.** Turn it so its 2.65 mm side runs across the board and its 3.5 mm side runs along the length — the other way round it doesn't fit at all.

---

## 4. Does it fit — the arithmetic

**Height, the tight one:**

```
  tallest top part (mic)      0.98
  PCB core                    0.60
  tallest bottom part         0.55
  ------------------------------
  board stack                 2.13
  battery thin step         + 2.60
  ------------------------------
  total                       4.73     cavity 5.40    margin 0.67  ✓
```

**Width:**

```
  widest footprint            3.00  (the decoupling row)
  board                       3.60     margin 0.60  ✓
  board in cavity             3.60     cavity 5.40  margin 1.80  ✓
```

**Length:**

```
  2.50  cap
 14.50  battery only
 13.00  board
  5.00  tip
 ------
 35.00  ✓
```

**Battery:** stepped pouch, 4.8 mm wide — 2.6 mm thick for 13 mm under the board, 4.6 mm thick for 14.5 mm above it. 482 mm³. At 225 Wh/L (measured from Grepow's ultra-narrow cell) that's **29.3 mAh**.

Allow the board to grow to 16 mm once routing is real and you get **27.6 mAh** — plan on that.

---

## 5. Talk time

| Recording draw | Talk time |
| --- | --- |
| 4 mA (optimized firmware) | 5.5 h |
| **6 mA (realistic)** | **3.7 h** |
| 8 mA (typical today) | 2.8 h |

Sanity check: **Oura Ring 4 is 26 mAh** in a smaller cross-section than this. 28 mAh in a 6 × 35 mm bar is not an aggressive claim.

---

## 6. Before you spend money

1. **Quote the stepped cell** (Grepow). Longest lead, only true custom part, and it sets the internal dimensions everything else works around.
2. **Choose the tactile switch.** Needs to be ≤2.5 × 1.6 mm, ≥150 µm travel, and rated for 100k presses.
3. **Prove the antenna** — a chip antenna in a dielectric tip on a 30 mm metal body. The maths is good (30 mm is 98% of an ideal quarter wave at 2.45 GHz) but it is still unproven in this exact geometry, and no arithmetic settles it.
4. **Buy the tube first.** 6 × 6 × 0.3 mm 316L square tube is a catalogue item and costs almost nothing. Hold it before committing to anything else.

**Do not order the custom board or the custom cell until the ugly dev-board version records, transmits, and transcribes.**

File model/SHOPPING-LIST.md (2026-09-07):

# Shopping list — checked for compatibility

Two carts. **Only order Cart 1 now.** Cart 2 is the production BOM and buying it today would waste money — those chips are 2 mm across with solder balls underneath and cannot be hand-soldered or used without a fabricated board.

---

## ⚠ Compatibility problem found — the BOM changed

**A lithium battery charges to 4.2 V. The nRF54L15's absolute maximum is 3.6 V.** You cannot run the chip from the battery directly; it would be destroyed on the first full charge.

The BQ25100 I listed earlier is a *charger only* — it manages charging but passes raw battery voltage through. It needs a separate regulator plus an inductor to step the voltage down.

**Fix: swap it for the Nordic nPM1100.** One 2.1 × 2.1 mm chip that is both the charger *and* a step-down regulator, with the output selectable at 1.8 / 2.1 / 2.7 / 3.0 V. It replaces two parts, solves the voltage problem, and is made by the same company as the main chip so they're designed to work together.

### Voltage rail — everything must agree

| Part | Works at | Notes |
| --- | --- | --- |
| nRF54L15 | 1.7 – 3.6 V | 1.8 V is uncomfortably close to its floor under load |
| T5837 mic | 1.6 – 3.6 V | happy either way |
| W25Q128J**W** flash | 1.65 – 1.95 V | **1.8 V part only** |
| W25Q128J**V** flash | 2.7 – 3.6 V | **3.3 V part** |

**Run the rail at 3.0 V and use the "JV" flash.** More headroom above the chip's minimum than 1.8 V gives you.

> **Verify before ordering:** confirm the JV is available in the 2.5 × 2.5 mm WLCSP package. If it's only offered in the larger package, drop the rail to 1.8 V and use the JW instead. **The rail and the flash must match** — a 1.8 V flash on a 3.0 V rail is destroyed instantly.

---

## Cart 1 — order today · ~$180 · arrives in days

Everything needed to answer the three questions that can kill the project. Nothing here is exotic.

| # | Item | Where | ~$ | Why |
| --- | --- | --- | --- | --- |
| 1 | **Seeed XIAO nRF52840 Sense** | [Seeed](https://www.seeedstudio.com/Seeed-XIAO-BLE-Sense-nRF52840-p-5253.html) · also Digi-Key, Amazon | 20 | Bluetooth chip, **microphone and battery charging already on it**. This is your whole prototype. |
| 2 | **Second XIAO or nRF52840 Dongle** | [Nordic dongle](https://www.nordicsemi.com/Products/Development-hardware/nRF52840-Dongle) · Digi-Key | 10–20 | The receiver, so you can measure signal strength through the steel. Without this the antenna test is guesswork. |
| 3 | **K&S 6 mm square brass/aluminium tube** | hobby shops · [Amazon](https://www.amazon.com/s?k=K%26S+precision+metals+square+tube+6mm) | 8 | The test enclosure. Brass behaves like steel for radio purposes and is far easier to cut. |
| 4 | **LiPo 3.7 V, 100–150 mAh** | Adafruit, Amazon | 8 | Runs it untethered. |
| 5 | **SMD/through-hole tactile switch assortment** | Amazon, Digi-Key | 8 | You'll want to feel several before picking one. |
| 6 | **PTFE or nylon rod, 6 mm** | Amazon, McMaster | 8 | The insulating gap that makes the antenna work. |
| 7 | **Digital calipers** | Amazon | 25 | Non-negotiable. Every number in this project is a fraction of a millimetre. |
| 8 | **The reference pendant, 40 × 4 mm** | The Steel Shop | 40 | Hold the size in your hand before committing to 6 mm. |
| 9 | Thin silicone sheet + fine mesh | Amazon | 12 | Mic mounting and port tests. |
| 10 | Chain and bails | **your Vancouver wholesale contact** | ~0 | Ask for ~4 mm rolo, and a leather cord to compare. |

**Buy 1, 2, 3 and 6 first if you want to move fastest** — that's the antenna test, and everything else waits on its answer.

---

## Cart 2 — production BOM · DO NOT ORDER YET

Correct and checked, so it's ready when the board is designed. These parts only become useful once you have a fabricated PCB and an assembly house.

| Part | Order number | Package | Source | Note |
| --- | --- | --- | --- | --- |
| SoC + BLE | **NRF54L15-CAAA-R** | CSP47, 2.45 × 2.25 | [Digi-Key](https://www.digikey.com/en/products/detail/nordic-semiconductor-asa/NRF54L15-CAAA-R) · Mouser | 0.3 mm pitch — needs HDI board and machine assembly |
| PMIC | **NPM1100-CAAA-R** | WLCSP 2.1 × 2.1 | [LCSC ~$0.91](https://www.lcsc.com/product-detail/Battery-Management-ICs_Nordic-Semicon-NPM1100-CAAA-R_C3682247.html) · Digi-Key | charger + buck. Set to 3.0 V |
| Microphone | **T5837** | 3.5 × 2.65 × 0.98 | [TDK](https://invensense.tdk.com/products/digital/t5837/) · Digi-Key | digital, no audio chip needed |
| Flash 16 MB | **W25Q128JV** (WLCSP) | 2.5 × 2.5 | Digi-Key, LCSC | **confirm package + 3.0 V match** |
| Crystal 32 MHz | **NX1612SA-32MHZ** | 1.6 × 1.2 | [JLCPCB C1986486](https://jlcpcb.com/partdetail/NDK-NX1612SA_32MHZ_EXS00ACS09166/C1986486) | no load caps needed — built into the SoC |
| Antenna | **2450AT18A100E** | 3.2 × 1.6 × 1.3 | Johanson · Digi-Key | goes in the black tip |
| Mic vent | **GORE GAW334** | Ø1.6 | Gore (sales enquiry) | IP68, <2 dB loss |
| Tactile switch | ≤2.5 × 1.6 mm | — | Digi-Key/Mouser filter | **still to choose** |
| Battery | Grepow custom stepped | 4.8 wide, 2.6/4.6 | [Grepow](https://www.grepow.com/shaped-battery/pouch-stepped-lipo-battery.html) | **quote now — longest lead item** |
| Passives | 0201 + 0402 inductor | — | LCSC (cheapest by far) | pennies |

### Compatibility summary

| Check | Result |
| --- | --- |
| Battery voltage vs SoC maximum | **was broken — fixed by the nPM1100** |
| Rail voltage across SoC, mic, flash | agree at 3.0 V (verify flash package) |
| Mic interface to SoC | digital PDM, native — direct connection |
| Flash interface to SoC | SPI, native |
| Crystal load capacitors | built into the SoC — 2 parts saved |
| Every part fits the 5.4 mm cavity | yes, 0.67 mm headroom |
| Antenna vs metal case | **unproven — this is Phase 0** |

---

## Cheapest and fastest, honestly

**Fastest:** Digi-Key and Mouser ship next-day to Canada and stock nearly everything in Cart 2. Amazon is fastest for the tube, calipers and silicone.

**Cheapest:** LCSC is dramatically cheaper for chips and passives (the nPM1100 is under a dollar there) but ships from China — a week or two, plus customs. Use LCSC when you order the real BOM; use Digi-Key/Amazon now, because a week of waiting costs more than a few dollars saved.

**JLCPCB** is worth knowing about for later: they fabricate *and* assemble boards, stock many of these parts themselves, and are far cheaper than assembling elsewhere. That's the Phase 4 route.

---

## The order to do things

1. **Order Cart 1 items 1, 2, 3, 6** today — about $56, arrives this week.
2. **Email Grepow for a stepped-cell quote** the same day. It costs nothing and it's the longest lead item in the project.
3. **Build the antenna test.** If Bluetooth can't escape the metal, everything else changes and you've spent $56 finding out.

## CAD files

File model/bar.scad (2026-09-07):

// ============================================================
//  THE BAR  —  6 x 6 x 35 mm  voice-note pendant
//  Every real component at its real coordinate.
//
//  VIEW options:
//    "assembled"  - the finished object
//    "ghost"      - see-through case, parts visible inside   <-- start here
//    "internals"  - just the parts, no case
//    "section"    - cut in half lengthways
//    "exploded"   - pulled apart
// ============================================================

VIEW = "ghost";

// ---------- THE BOX ----------
L    = 35.0;   // total length
W    = 6.0;    // width and depth (square)
WALL = 0.3;    // tube wall
CH   = 0.35;   // edge chamfer
CAV  = W - 2*WALL;            // 5.4 cavity

// ---------- ZONES DOWN THE LENGTH ----------
CAP_T  = 2.5;                 // top cap + chain bail
BATT_L = 14.5;                // battery only, thick step
BOARD_L= 13.0;                // board over the thin battery step
TIP_L  = 5.0;                 // black dielectric tip: antenna + light

Y_BATT  = CAP_T;
Y_BOARD = CAP_T + BATT_L;
Y_TIP   = L - TIP_L;

// ---------- BATTERY (custom stepped pouch) ----------
CELL_W  = 4.8;
CELL_T1 = 2.6;   // thin step, sits under the board
CELL_T2 = 4.6;   // thick step, fills the bar above the board

// ---------- BOARD ----------
PCB_W = 3.6;
PCB_T = 0.6;
// board sits on top of the thin battery step, with room underneath for the
// bottom-side components (0.55 tall). cell top = -CAV/2 + CELL_T1 = -0.1
PCB_Z = -CAV/2 + CELL_T1 + 0.55 + PCB_T/2;   // = 0.75

$fn = 40;

// ============================================================
//  HELPERS   (+Y runs DOWN the bar from the top)
// ============================================================

module bar_solid(len, width, ch=CH) {
    hull() {
        translate([0,-len,0]) linear_extrude(.01) square([width-2*ch, width], center=true);
        translate([0,-len,0]) linear_extrude(.01) square([width, width-2*ch], center=true);
        linear_extrude(.01) square([width-2*ch, width], center=true);
        linear_extrude(.01) square([width, width-2*ch], center=true);
    }
}

module tube(len) {
    difference() {
        bar_solid(len, W);
        translate([0,.01,0]) bar_solid(len+.02, CAV, ch=.15);
    }
}

// a component: x = mm from LEFT edge of board, y = mm down the BAR, z-up or z-down
module part(name, xoff, ybar, xs, ys, zh, up=true) {
    zbase = up ? PCB_Z + PCB_T/2 : PCB_Z - PCB_T/2 - zh;
    translate([-PCB_W/2 + xoff, -ybar - ys, zbase])
        cube([xs, ys, zh]);
}

// ============================================================
//  THE CASE
// ============================================================

module case_metal() {
    color("#C2C9CE") difference() {
        union() {
            translate([0,-CAP_T,0]) bar_solid(CAP_T, W);       // top cap
            translate([0,-Y_TIP,0]) tube(Y_TIP - CAP_T);       // the tube
        }
        // button bore, +X side face, centred 22.15 mm down
        translate([W/2, -22.15, 0]) rotate([0,90,0]) translate([0,0,-W]) cylinder(d=2.7, h=W);
        // mic port, +Z front face, 19.15 mm down
        translate([0, -19.15, W/2]) translate([0,0,-W]) cylinder(d=1.2, h=W);
        translate([0, -19.15, W/2-0.25]) cylinder(d=2.6, h=1);   // mesh recess
    }
    // chain bail
    color("#C2C9CE") translate([0, 1.2, 0]) rotate([90,0,0])
        rotate_extrude() translate([1.5,0]) circle(d=0.9);
}

module tip() {
    color("#22282B", 0.9) translate([0,-L,0]) bar_solid(TIP_L, W);
    // two charge pads on the bottom face
    color("#C9A227") for (x=[-1.2,1.2])
        translate([x, -L+0.1, 0]) rotate([90,0,0]) cylinder(d=1.6, h=0.3);
}

module pusher() {
    color("#E3E9ED") translate([W/2-0.05, -22.15, 0]) rotate([0,90,0])
        translate([0,0,-0.9]) cylinder(d=2.6, h=0.9);
    color("#141414") translate([W/2-0.8, -22.15, 0]) rotate([0,90,0])
        rotate_extrude() translate([1.45,0]) circle(d=0.4);
}

module mesh() {
    color("#394146") translate([0,-19.15,W/2-0.22]) cylinder(d=2.6, h=0.22);
}

// ============================================================
//  INTERNALS
// ============================================================

module battery() {
    color("#7A5230", 0.95) {
        // thick step — beside/above the board
        translate([-CELL_W/2, -Y_BOARD, -CELL_T2/2])
            cube([CELL_W, BATT_L, CELL_T2]);
        // thin step — tucked under the board
        translate([-CELL_W/2, -Y_TIP, -CAV/2])
            cube([CELL_W, BOARD_L, CELL_T1]);
    }
}

module board() {
    // the bare PCB
    color("#164D32") translate([-PCB_W/2, -Y_TIP, PCB_Z - PCB_T/2])
        cube([PCB_W, BOARD_L, PCB_T]);

    // ---- BOTTOM SIDE (faces the battery) ----
    color("#101010") part("SoC",     0.57, 17.40, 2.45, 2.25, 0.50, up=false);
    color("#101010") part("flash",   0.55, 20.10, 2.50, 2.50, 0.33, up=false);
    color("#101010") part("charger", 1.00, 23.05, 1.60, 0.90, 0.50, up=false);
    color("#9A8C5A") part("crystal", 1.00, 24.40, 1.60, 1.20, 0.35, up=false);
    color("#3A3A3A") part("rfmatch", 0.90, 26.05, 1.80, 0.30, 0.30, up=false);
    color("#3A3A3A") part("decap",   0.30, 26.80, 3.00, 0.60, 0.30, up=false);
    color("#4A4A4A") part("inductor",1.30, 27.85, 1.00, 0.50, 0.55, up=false);
    color("#B08D3A") part("padsp",   1.20, 28.80, 1.20, 0.80, 0.05, up=false);

    // ---- TOP SIDE (faces the case wall) ----
    color("#2A2A2A") part("mic",     0.48, 17.40, 2.65, 3.50, 0.98, up=true);
    color("#1A1A1A") part("switch",  0.55, 21.35, 2.50, 1.60, 0.80, up=true);
    color("#C94A2E") part("led",     1.30, 29.10, 1.00, 0.50, 0.45, up=true);

    // chip antenna, sitting inside the black tip
    color("#D8D8D8") translate([-1.6, -(L-1.2), -0.65]) cube([3.2, 1.6, 1.3]);
}

module internals() { battery(); board(); }

// ============================================================
//  VIEWS
// ============================================================

module full(explode=0) {
    translate([0,  explode*2, 0]) case_metal();
    translate([0, -explode*2, 0]) tip();
    translate([ explode*3, 0, 0]) pusher();
    translate([0, 0, explode*3]) mesh();
}

if (VIEW == "assembled") { full(); }

else if (VIEW == "ghost") {
    %full();          // transparent case
    internals();
}

else if (VIEW == "internals") { internals(); }

else if (VIEW == "exploded") {
    full(explode=2);
    translate([0,0,-9]) internals();
}

else if (VIEW == "section") {
    difference() { full(); translate([0,-L-2,-W]) cube([W,L+4,2*W]); }
    difference() { internals(); translate([0,-L-2,-W]) cube([W,L+4,2*W]); }
}

// ---------- checks printed to the console ----------
echo(str("LENGTH  ", CAP_T,"+",BATT_L,"+",BOARD_L,"+",TIP_L," = ",
         CAP_T+BATT_L+BOARD_L+TIP_L, " mm   (target ", L, ")"));
echo(str("CAVITY  ", CAV, " mm square"));
echo(str("STACK   mic 0.98 + pcb ", PCB_T, " + bottom 0.55 + cell ", CELL_T1,
         " = ", 0.98+PCB_T+0.55+CELL_T1, " mm  vs cavity ", CAV,
         "  -> margin ", CAV-(0.98+PCB_T+0.55+CELL_T1)));
echo(str("TOP OF MIC at z=", PCB_Z+PCB_T/2+0.98, "  cavity roof z=", CAV/2,
         "  -> clearance ", CAV/2-(PCB_Z+PCB_T/2+0.98)));
echo(str("WIDTH   board ", PCB_W, " in cavity ", CAV, " -> margin ", CAV-PCB_W));

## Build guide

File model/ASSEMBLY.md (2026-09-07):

# The Bar — assembly model

How it actually goes together. Numbers verified; the stack closes.

3D model: `bar.scad` — open in [OpenSCAD](https://openscad.org) (free), press F5. Change `VIEW` at the top for `assembled` / `exploded` / `section` / `internals` / `dock`.

---

## 1. The layout, and why it's this order

```
   ○  chain bail (solid, part of the cap)
 ┌───┐  0.0
 │CAP│  top cap ........................ 4.0 mm
 ├───┤  4.0
 │   │
 │BAT│  battery bay ................... 24.0 mm   ← upper half
 │   │
 ├───┤  28.0
 │▓▓▓│  BAND — antenna gap + light ..... 2.5 mm   ← the split
 ├───┤  30.5
 │ ◉ │  mic + mesh at 34 mm
 │PCB│  electronics bay ............... 25.1 mm   ← lower half
 │ ● │  button at 45 mm
 ├───┤  55.6
 │CAP│  bottom cap + charge pads ....... 4.0 mm
 └───┘  59.6  (+0.4 assembly clearance = 60)
```

**Why the battery is on top and the electronics are at the bottom** — this is the one non-obvious decision, and it's forced by the antenna.

The band splits the steel into two electrically separate halves. That's the entire point: the two halves become the two arms of the antenna. But it means **nothing conductive can bridge the gap**, or the two halves short together and the antenna dies. A PCB running the full length with a ground plane would do exactly that.

So: all electronics live entirely in the lower half. The battery lives entirely in the upper half. Only **two thin wires** cross the gap, each with a ferrite bead that blocks radio frequencies while passing DC. This is precisely the approach in Oura's antenna patent (US 11,349,191).

Three things fall out of that for free:

- The **button lands in the lower third** — exactly where you wanted it, and where your thumb naturally sits on a hanging pendant.
- The **charge pads are next to the charging circuit**, so no power routing crosses the gap.
- The **band sits at 28 mm**, giving antenna arms of 28 and 32 mm. Near-symmetric is the easiest case to match.

**Cost of moving the band lower:** at 40 mm you get 40/20 mm arms. It still radiates, but the feed impedance climbs and you need a proper matching network — call it 1–3 dB. Decide this with your eyes; just know it isn't free.

---

## 2. Cross-section — the 6 mm is mostly wall and air

```
        6.00 mm
   ┌──────────────┐
   │░░░░░░░░░░░░░░│  0.4 wall
   │░┌──────────┐░│
   │░│          │░│  cavity 5.2 × 5.2
   │░│  ▄▄▄▄▄▄  │░│  PCB 3.6 wide
   │░│          │░│
   │░└──────────┘░│
   │░░░░░░░░░░░░░░│
   └──────────────┘
```

| Needs | Width | Fits in 5.2 | Margin |
| --- | --- | --- | --- |
| Battery cell | Ø4.5 | yes | 0.70 |
| PCB | 3.6 | yes | 1.60 |
| Button boss + O-ring | 3.6 | yes | 1.60 |
| Mic package | 2.65 | yes | 2.55 |

Everything clears. The battery is the tight one — 0.7 mm of total slack means the cell needs a thin heat-shrink sleeve and nothing else.

---

## 3. The band does three jobs

One part, three functions — which is why it's worth the manufacturing trouble.

**1 · It's the antenna.** Without a non-metal gap, a sealed steel tube attenuates Bluetooth about 6 dB per millimetre. The radio isn't weak, it's silent. The gap turns the case into the antenna.

**2 · It's the recording light.** Make the band from a *translucent* polymer or ceramic and put one LED inside against it. The entire ring glows when recording — visible from every angle, no extra hole in the case, no window to seal. Cost: one LED and one resistor.

This is the answer to "should there be a light." A hole for an LED would breach the waterproofing; the band is already a non-metal window, so it's free.

**3 · It's the design accent.** A dark or coloured ring across polished steel, near the lower third. Exactly the detail you described — and now it's structural, functional, and decorative at once.

**Material:** a translucent glass-filled polymer bonded by nano-moulding (NMT), which also forms the waterproof seal. Zirconia is the premium alternative but is only faintly translucent — less good as a light pipe.

**Structurally it's fine.** The chain pulls on the *top* cap, so the band only ever carries the weight of the lower half — about 5 grams. It is not in the main load path.

---

## 4. The button

| Piece | Spec |
| --- | --- |
| Pusher | Ø2.6 mm steel, flush with the face when idle |
| Travel | 0.25 mm |
| Seal | Ø0.45 mm O-ring in a groove around the pusher |
| Switch | SMD tactile dome on the PCB directly beneath |
| Position | side face, 45 mm from top |

Ø2.6 mm on a 6 mm face leaves 1.7 mm of steel each side — proportionally it reads as a deliberate detail rather than a hole.

**Interaction, as you specified:**

| Input | Result |
| --- | --- |
| Single click | **nothing** — deliberate, so a bump against a desk can't start a recording |
| Double click | starts recording, band glows. Click again to stop |
| Press and hold | records while held, stops on release |

Both modes are firmware only — no extra parts.

**Side, not the bottom end.** A pendant hangs free, so pressing the bottom just swings it or tugs the chain. On the side you pinch it — thumb on the button, finger behind as backing — which is a stable, one-handed, eyes-free gesture.

---

## 5. Microphone

Port Ø1.2 mm on the front face at 34 mm, just below the band, with a Ø2.6 mm mesh disc recessed 0.25 mm so it sits flush.

The mesh is the Gore ePTFE membrane — waterproof to IP68, under 2 dB of acoustic loss — and it reads as an intentional design mark, not a hole.

**Why the mic is in the lower half, not up near your mouth:** it has to be on the same side of the band as the chip. Moving it 30 mm lower adds about 10% to the mouth-to-mic distance, which is roughly **1 dB** — inaudible. Routing four microphone signals across the antenna gap would cost far more than that.

The mic sits in a silicone boot so it never touches steel. Without that the whole bar behaves as a contact microphone and every chain link tick is louder than your voice.

---

## 6. Charging

**On the pendant:** two Ø1.6 mm gold pads on the bottom cap. Only two are needed — audio leaves over Bluetooth, so the dock carries power only.

**The dock:** a weighted block with a shallow channel milled to the bar's profile. Drop the bar in, magnets pull it onto the pins, the chain drapes over a relief notch. No cable to plug, no orientation to get right, nothing to align.

That matches the ritual you described — chain off, drop it in the dish, it charges.

Keep the pads **unpowered until the dock senses a valid load**. A permanent DC voltage across two exposed pads will electrolytically pit them within weeks of sweat exposure.

---

## 7. Assembly sequence

The order matters — some steps are irreversible.

1. **Populate and test the PCB flat**, before anything goes near a tube. Verify recording and Bluetooth on the bench.
2. **Bond the mic** to its silicone boot; fold the flex tail.
3. **Solder the battery tabs** directly to the board. Two wires with ferrite beads bridge what will become the band gap. No connectors anywhere.
4. **Fit the pusher and O-ring** into the lower tube; check the click through the wall.
5. **Slide the electronics into the lower tube** from its open top end, aligning the switch under the pusher.
6. **Bond the band** to the lower tube; seat the LED against it.
7. **Slide the battery into the upper tube**, then bond the upper tube to the band.
8. **Seal the mic mesh** over its port.
9. **Bond both end caps** last. From here it's a closed object with no service access.
10. **Test submerged** before calling it done.

**There is no rework path after step 9.** Everything that can be tested must be tested before the caps go on.

---

## 8. What is most likely to go wrong

| Risk | Why | What to do |
| --- | --- | --- |
| **Antenna doesn't radiate** | untested; depends on your exact build | Phase 0, before anything else |
| Band joint fails | it's a bonded butt joint in a thin wall | mechanical interlock, not adhesive alone |
| Button leaks | O-ring gland is tight in a 6 mm boss | pressure-test 20 units before committing |
| Cell doesn't fit | 0.70 mm total slack | buy the exact cell before finalising the tube |
| Chain noise | metal bar on metal chain | silicone mic boot; offer leather |
| No service access | fully bonded | accept it — this is a sealed product |

---

## 9. Model status

`bar.scad` is written but **not yet rendered** — OpenSCAD isn't installed on this machine, so the geometry hasn't been visually confirmed. Install with:

```
brew install --cask openscad
```

Then open the file and press F5. Print `VIEW = "assembled"` at 1:1 in resin to hold the real size before ordering any steel.

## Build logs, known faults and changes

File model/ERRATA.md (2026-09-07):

# Errata — audit of the whole design, 2026-08-05

Eight errors found. Three are serious. Nothing below is an excuse; where I don't have a solution I say so.

---

## SERIOUS — must be fixed before spending money

### 1. The button does not work. The design is wrong.

In `bar.scad` the tactile switch is placed with `up=true`, which puts it facing the **front** face (+Z). The pusher enters through the **side** face (+X). They are perpendicular. **The pusher would press into empty space beside the switch.**

This is a real geometry error in the model and in `PARTS-AND-LAYOUT.md`, which shows the button on the side face and the switch on the board's top side.

**Solution:** the switch and the pusher must face the same direction. Two options:

- **Move the button to the front face**, alongside the mic port. Both features then sit on one face at different heights (mic at 19 mm, button at 22 mm). Simplest fix, no new parts.
- **Rotate the board 90°** inside the tube so its component side faces sideways. Then the mic port moves to the side face too.

Recommended: put the button on the front face. But note this contradicts the ergonomics I argued for earlier — pinching the bar puts your thumb on the *side*, not the front. **A decision is needed, and it changes the industrial design.**

### 2. The Phase 0 antenna test as written is impossible

Cart 1 says to put the XIAO nRF52840 Sense inside a 6 mm tube.

```
XIAO nRF52840 Sense : 21.0 x 17.5 x 3.5 mm
6 mm tube cavity    :  5.4 x  5.4 mm
Does not fit — off by 12.1 mm
```

The dev board is three times too wide. The test I told you to run cannot be performed with the parts I told you to buy.

**Solution:** the test must feed radio energy *into* the tube from outside, over a thin coaxial cable. That requires a board with an external antenna connector (u.FL / IPEX), which the XIAO does not have.

- Buy an **nRF52840 module or dongle with a u.FL connector** (Fanstel BT840F, or a Raytac MDBT50Q-RX dongle in the external-antenna variant) instead of relying on the XIAO for this test.
- Solder a thin coax (RG-178 or 1.13 mm) to the split tube, feed it from that board, and measure received strength on a second board across the room.

The XIAO is still the right part for the *recording* prototype (Phases 1–3). It is the wrong part for the antenna test.

### 3. There is no battery protection in the BOM, and it costs length I have not budgeted

A lithium cell needs protection against over-discharge, over-current and short circuit. My parts list has none. The nPM1100 protects the *charging* path; it is not a substitute for cell protection on the cell itself.

Custom pouch cells normally ship with a small protection board (PCM) welded to the tabs, typically **3–5 mm long**. My 35 mm budget assumed a bare cell with no PCM.

**Consequence:** the bar grows to roughly **38–40 mm**, or the battery shrinks by 3–5 mm of length (about 4–6 mAh, so roughly 30–45 minutes of talk time).

**A solution must be found, and it is a real trade:** either accept ~39 mm, accept less runtime, or ask Grepow whether the PCM can be folded beside the cell rather than sitting in line with it. I do not know the answer to the third option — it has to be a question in the quote request.

---

## REAL, BUT MANAGEABLE

### 4. Charge current is at the limit of the cell

nPM1100's minimum selectable charge current is **20 mA**. On a 28 mAh cell that is **0.71C**.

Many small pouch cells accept 1C, so this is probably fine — but "probably" is not verification. **Confirm the cell's maximum charge current in the Grepow quote.** If it is below 20 mA, the nPM1100 cannot charge it slowly enough and a different PMIC is required.

### 5. I contradicted myself on the board's layer count

I wrote "4-layer rigid-flex" in `PARTS-AND-LAYOUT.md` and the 3D viewer, and "6-layer HDI" elsewhere.

**6-layer HDI is correct.** The nRF54L15 CSP has 0.3 mm ball pitch, and Nordic's own guidance is explicit that there is no escape routing for these packages on ordinary boards — it needs laser microvias and via-in-pad. The 4-layer figure is wrong and would make the board cheaper than it will actually be.

### 6. The talk-time figure may be optimistic by 2×

I quoted **3.7 hours**, based on a 6 mA recording draw. That number is my estimate of a well-optimised design, not a measurement.

| Draw | Talk time |
| --- | --- |
| 4 mA — optimistic | 5.6 h |
| 6 mA — what I quoted | 3.7 h |
| **13 mA — what Plaud and Omi actually draw** | **1.7 h** |

Shipping products in this category draw 11–16 mA. If the firmware lands there rather than where I assumed, you get **1.7 hours, not 3.7**. That is still a usable product, but it is half what I told you.

**This can only be settled by measurement**, in Phase 1, on the dev board. Until then treat 1.7–3.7 hours as the honest range.

### 7. Two charge pads means no way to program the device after assembly

I specified 4 contacts early on, then cut to 2 when audio moved to Bluetooth. With only power and ground, there is no debug connection once the board is inside the tube.

**Solution:** go back to **4 pads** — power, ground, and the two programming lines (SWDIO/SWCLK). The cost is nothing; the alternative is that any firmware problem after assembly leaves you with a sealed brick, and over-the-air updates cannot recover a device whose radio code is broken.

### 8. My own documents describe two different products

`PENDANT-PLAN.md` describes a **thin black band across the middle** at 28 mm, splitting the bar into a dipole. `FIT-STUDY.md`, `PARTS-AND-LAYOUT.md`, the CAD model and the 3D viewer all describe a **5 mm black tip at the bottom** with a chip antenna inside.

These are incompatible designs and both are in your project folder. The tip version is the current one — it followed from the stacked-battery layout, which leaves no room for a mid-body split. `PENDANT-PLAN.md` is out of date and needs rewriting.

---

## What still has no answer

**Whether the antenna radiates at all.** Unchanged, and unaffected by everything above. A chip antenna in a 5 mm dielectric tip on a 30 mm metal body is sound in theory — 30 mm is 98% of an ideal quarter wave — but it is unproven in this geometry, and no amount of calculation settles it. It remains the one thing that can invalidate the whole product.

---

## Revised honest summary

| | Was | Now |
| --- | --- | --- |
| Length | 35 mm | **38–40 mm** once cell protection is included |
| Talk time | 3.7 h | **1.7–3.7 h** until measured |
| Board | 4-layer | **6-layer HDI** — more expensive |
| Button | side face | **unresolved** — front face works, side face needs a redesign |
| Charge pads | 2 | **4** |
| Antenna | unproven | unproven |

None of this makes the product impossible. All of it would have surfaced later and more expensively.
